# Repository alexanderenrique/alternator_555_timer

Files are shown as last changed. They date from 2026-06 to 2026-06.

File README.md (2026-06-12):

# Alternator 555 Timer

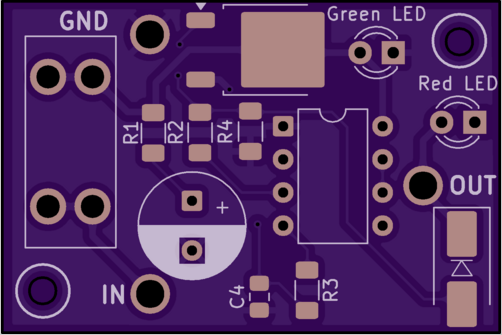
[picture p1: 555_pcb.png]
Alternator 555 Timer PCB layout


A small analog delay board for classic cars with upgraded alternators. A CMOS 555 monostable holds the alternator field (I wire) off for ~10 seconds after key-on so V-belts can spin up before the load hits — no MCU, no firmware.

**Project page:** [denton.works/projects/alternator-555-timer](https://denton.works/projects/alternator-555-timer/)

## What's here

- KiCad schematic and PCB (`555_I_delay.kicad_*`)
- `BOM.csv` — bill of materials
- `555_v1.zip` — zipped gerbers and drill files for your PCB manufacturer

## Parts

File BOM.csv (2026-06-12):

Reference | Qty | Value | Footprint | Description
C1,C3,C4 | 3 | 0.1uF | Capacitor_SMD:C_0805_2012Metric_Pad1.18x1.45mm_HandSolder | Pulls Trig to ground momenterily,Smoothing Capacitor,Smoothing capacitor
C2 | 1 | 47uF | Capacitor_THT:CP_Radial_D8.0mm_P3.80mm | Electrolytic capcitor for RC timing circuit
D1,D2 | 2 | SZ1SMB15AT3G | Diode_SMD:D_SMB_Handsoldering | Gate/Drain TVS protection,Supply voltage TVS
D3 | 1 | Green LED | LED_THT:LED_D3.0mm_Clear | Light emitting diode
D4 | 1 | Red LED | LED_THT:LED_D3.0mm_Clear | Light emitting diode
F1 | 1 | Fuse_Small | Fuse:Fuseholder_Blade_Mini_Keystone_3568 | Fuse, 10A
J1 | 1 | I_In | Connector_Pin:12_AWG_TH_Alex | Wire Mounting hole
J2 | 1 | I_out | Connector_Pin:12_AWG_TH_Alex | Generic connector, single row, 01x01, script generated
J3 | 1 | GND_Conn | Connector_Pin:12_AWG_TH_Alex | Chassis and circuit ground
Q1 | 1 | FQD11P06TM | Package_TO_SOT_SMD:TO-252-2 | -27A Id, -60V Vds, QFET P-Channel MOSFET, TO-220
R1 | 1 | 220k | Resistor_SMD:R_1206_3216Metric_Pad1.30x1.75mm_HandSolder | Resistor for RC timing circuit
R2 | 1 | 100 | Resistor_SMD:R_1206_3216Metric_Pad1.30x1.75mm_HandSolder | Resistor to minimize line ringing
R3 | 1 | 10k | Resistor_SMD:R_1206_3216Metric_Pad1.30x1.75mm_HandSolder | Raises trig up after initial start
R4 | 1 | 100k | Resistor_SMD:R_1206_3216Metric_Pad1.30x1.75mm_HandSolder | MOSFET pull-down resistor
U1 | 1 | TLC555CP | Package_DIP:DIP-8_W7.62mm | CMOS 555 compatible, PDIP-8

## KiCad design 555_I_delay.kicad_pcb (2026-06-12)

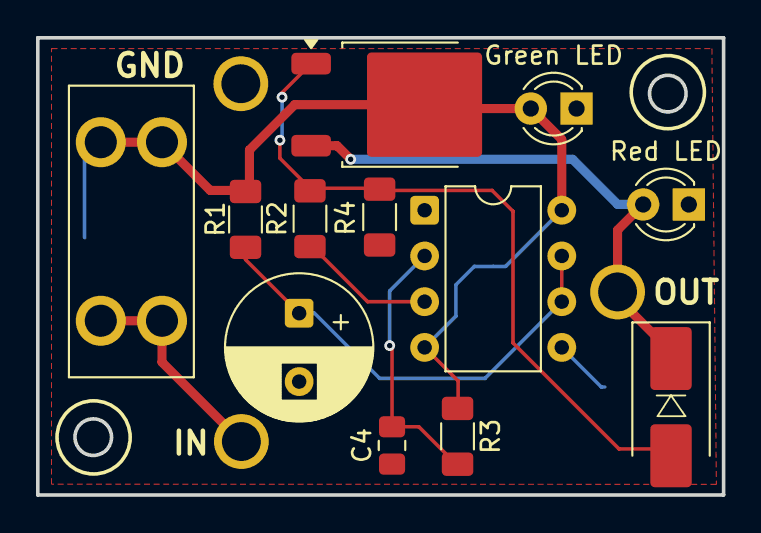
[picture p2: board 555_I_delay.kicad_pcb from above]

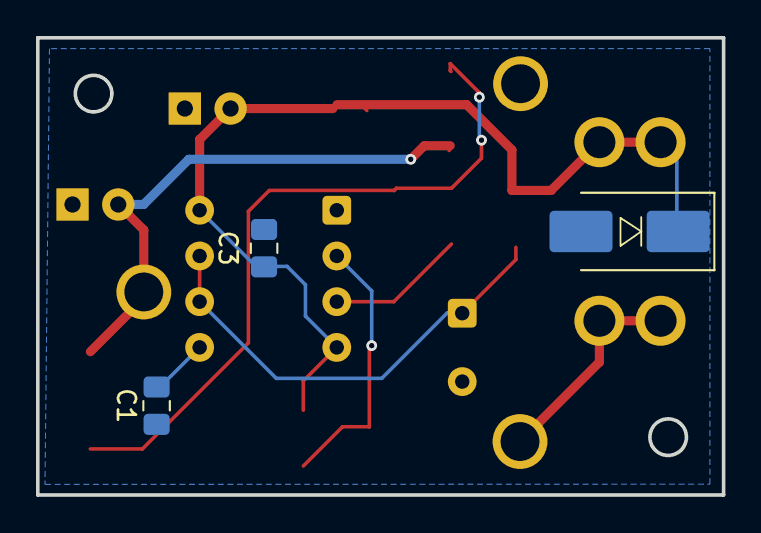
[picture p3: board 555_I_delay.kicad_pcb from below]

Board: 2 copper layers, 38.1 x 25.4 mm, 18 parts (3 on the bottom side), 9 nets.

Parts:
C1, C3, C4: 0.1uF; C_0805_2012Metric_Pad1.18x1.45mm_HandSolder
C2: 47uF; CP_Radial_D8.0mm_P3.80mm
D1: TVS; D_SMB_Handsoldering
D2: BZV55B15; D_SMB_Handsoldering
D3: Green LED; LED_D3.0mm_Clear
D4: Red LED; LED_D3.0mm_Clear
F1: Fuse_Small; Fuseholder_Blade_Mini_Keystone_3568
J1: I_In; PinHeader_1x01_P1.00mm_Vertical
J2: I_out; 12_AWG_TH_Alex
J3: GND_Conn; 12_AWG_TH_Alex
Q1: FQD11P06TM; TO-252-2
R1: 220k; R_1206_3216Metric_Pad1.30x1.75mm_HandSolder
R2: 100; R_1206_3216Metric_Pad1.30x1.75mm_HandSolder
R3: 10k; R_1206_3216Metric_Pad1.30x1.75mm_HandSolder
R4: 100k (pulldown); R_1206_3216Metric_Pad1.30x1.75mm_HandSolder
U1: NE555P; DIP-8_W7.62mm

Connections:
GND: C1.1, C2.2, C3.1, C4.1, D2.2 (A), D3.1 (K), D4.1 (K), J3.1 (Pin_1_1), R4.2, U1.1 (GND)
unnamed: D1.2 (A), Q1.1 (G), R2.2, R4.1
unnamed: D1.1 (K), D4.2 (A), J2.1 (Pin_1_1), Q1.3 (S)
unnamed: C3.2, D2.1 (K), D3.2 (A), F1.2, Q1.2 (D), R1.1, R3.1, U1.4 (~RST), U1.8 (VCC)
unnamed: F1.1, J1.1 (Pin_1_1)
unnamed: C1.2, U1.5 (CONT)
unnamed: C2.1, R1.2, U1.6 (THRES), U1.7 (DISCH)
unnamed: R2.1, U1.3 (OUT)
unnamed: C4.2, R3.2, U1.2 (TRIG)

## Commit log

2026-06-12 Initial commit: KiCad PCB for alternator field delay circuit.
    555 monostable timer board with gerber manufacturing outputs.
    [555_I_delay-B_Cu.gbr, 555_I_delay-B_Mask.gbr, 555_I_delay-B_Paste.gbr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]
2026-06-12 added BOM
    [555_I_delay.csv, 555_I_delay.kicad_sch]
2026-06-12 cleaned up
    [555_I_delay-B_Cu.gbr, 555_I_delay-B_Mask.gbr, 555_I_delay-B_Paste.gbr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]
2026-06-12 Document BOM and manufacturer zip in README; add 555_v1.zip to repo.
2026-06-12 Ignore KiCad project local settings; add PCB image to README.
